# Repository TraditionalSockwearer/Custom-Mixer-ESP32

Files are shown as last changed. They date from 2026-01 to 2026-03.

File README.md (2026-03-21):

# Custom Mixer ESP32 (v2.0)

This project uses an ESP32 to read 5 linear faders, 2 rotary encoders, and 18 switches, with programmable buttons acting like MIDI and everything that happens, as a change in volume will show on the 2.2-inch screen.

This project's purpose is to act as a mixer and control the volume of an app when it sounds too loud or too quiet.

The Rotary Encoders will be used as a selector to scroll through active apps and the slider they should be on, or potentially as a master volume control.

## Schematic



## PCB

aab3a241-1
aab3a241-2

## CAD





## Quick Start

### 1. Flash the ESP32-S3 Firmware

1. Install [CircuitPython 9.x](https://circuitpython.org/board/espressif_esp32s3_devkitc_1_n8r8/) on your ESP32-S3
2. Copy `Firmware/esp32/main.py` and `Firmware/esp32/boot.py` to the **CIRCUITPY** drive
3. Copy these libraries to the `/lib` folder on the drive (from the [CircuitPython Bundle](https://circuitpython.org/libraries)):
   - `adafruit_ili9341.mpy`
   - `adafruit_display_text/`
   - `adafruit_bus_device/`

### 2. Run the PC Software

```bash
pip install pycaw pyserial pystray psutil Pillow pywin32 obs-websocket-py
python Firmware/mixer.py --console
```

Run `python Firmware/mixer.py --help` for all options (COM port override, test mode, etc.).

> Requires **Windows 10/11**, **Python 3.10+**, and optionally **EqualizerAPO** (for EQ mode) and **OBS with WebSocket** (for OBS channel).

## Firmware

[View detailed firmware documentation](Firmware/README.md)

## BOM

The complete list of hardware required to build this project.

### Digikey

| Part | Description | Qty | Price |
| :--- | :--- | :--- | :--- |
| **[PTA6043-2015CPB103](https://www.digikey.co.uk/en/products/detail/bourns-inc/PTA6043-2015CPB103/3781230)** | Bourns — Slide Pot 10K, 60mm | 5 | £7.10 |
| **[K104K10X7RF5UH5](https://www.digikey.co.uk/en/products/detail/vishay-beyschlag-draloric-bc-components/K104K10X7RF5UH5/2356754)** | Vishay — Ceramic Cap 0.1µF 50V | 10 | £1.13 |
| **[ECA-1EM101B](https://www.digikey.co.uk/en/products/detail/panasonic-electronic-components/ECA-1EM101B/268461)** | Panasonic — Electrolytic Cap 100µF 25V | 2 | £0.46 |
| **[PEC11R-4215F-S0024](https://www.digikey.co.uk/en/products/detail/bourns-inc/PEC11R-4215F-S0024/4499665)** | Bourns — Rotary Encoder | 2 | £3.30 |
| **[PRPC040SAAN-RC](https://www.digikey.co.uk/en/products/detail/sullins-connector-solutions/PRPC040SAAN-RC/2775214)** | Sullins — 40-Pin Header | 3 | £1.23 |
| **[RNF14FTD10K0](https://www.digikey.co.uk/en/products/detail/stackpole-electronics-inc/RNF14FTD10K0/1706596)** | Stackpole — 10K Resistor 1/4W | 10 | £0.30 |
| **[CFR-50JT-52-4K7](https://www.digikey.co.uk/en/products/detail/yageo/CFR-50JT-52-4K7/9099664)** | YAGEO — 4.7K Resistor 1/2W | 10 | £0.34 |
| **[OEJL-90-4-5](https://www.digikey.co.uk/en/products/detail/kilo-international/OEJL-90-4-5/710678)** | Kilo International — Solid Aluminium Knob | 2 | £18.68 |
| **[1300-B](https://www.digikey.co.uk/en/products/detail/davies-molding-llc/1300-B/7908413)** | Davies Molding — Nylon Knob | 5 | £3.86 |
| **[MCP23017-E/SP](https://www.digikey.co.uk/en/products/detail/microchip-technology/MCP23017-E-SP/894272)** | Microchip — I²C I/O Expander 28-SDIP | 2 | £2.54 |

Digikey Total: £45.37

### AliExpress

| Part | Description | Qty | Price |
| :--- | :--- | :--- | :--- |
| **[2.2" TFT LCD](https://www.aliexpress.com/item/1005008143782445.html)** | 2.2" ILI9341 Full Color TFT (includes shipping) | 1 | £5.22 + £3.32 shipping |
| **[ESP32-S3-WROOM-1 N16R8](https://www.aliexpress.com/item/1005008796158734.html)** | ESP32-S3 Dev Board, 44-Pin, 8M PSRAM | 1 | £5.28 |
| **Cherry MX Switches** | Pre-owned mechanical switches | 18 | £0.00 |

Estimated AliExpress Total: £13.82 without discount

### Manufacturing

| Part | Description | Qty | Price |
| :--- | :--- | :--- | :--- |
| **[JLCPCB PCB](https://jlcpcb.com/)** | PCB prototype (black, 1.6mm, HASL with lead) | 5 | $13.10 |

JLCPCB Total: $21.08 or £15.80

For 3D printing, filament is about £10.25 from Bambu Labs.

**Grand Total: £85.24**

## KiCad Libraries

- [SSD1306 OLED Footprint](https://github.com/gorbachev/KiCad-SSD1306-0.91-OLED-4pin-128x32.pretty/tree/master)
- [ESP32-DEVKITC-32E](https://www.snapeda.com/parts/ESP32-DEVKITC-32E/Espressif%20Systems/view-part/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)
- [PEC12R Rotary Encoder](https://www.snapeda.com/parts/PEC12R-4217F-S0024/Bourns/view-part/?ref=search&t=rotary%20encoder)
- [Adafruit 2717](https://www.snapeda.com/parts/2717/Adafruit%20Industries/view-part/)
- [PTA4543 Slide Pot](https://www.snapeda.com/parts/PTA4543-2015DPA103/Bourns/view-part/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)
- [0.91" OLED 3D Model](https://grabcad.com/library/0-91-oled-display-module-1/files?folder_id=13981557)

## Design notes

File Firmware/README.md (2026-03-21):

# Custom Mixer

Companion software and firmware for a custom digital mixer built around an ESP32-S3.

## Overview

5 faders, 2 rotary encoders, and a 2.2" color TFT on an ESP32-S3. Controls system audio, per-app volume, microphone input, OBS, and headphone EQ from one device.

## Structure

```
mixer.py              ← single PC script (run this)
Firmware/esp32/       ← CircuitPython firmware for ESP32-S3
```

### Channel Layout

| Fader | Control |
|---|---|
| 1 | Master Volume |
| 2 | App 1 (cycle with encoder) |
| 3 | App 2 (cycle with encoder) |
| 4 | Microphone Input |
| 5 | OBS Desktop Audio |

### EQ Mode

Button 1 toggles EQ mode — faders map to 80Hz, 320Hz, 1kHz, 3.2kHz, 10kHz via EqualizerAPO.

## Usage

```bash
pip install pycaw pyserial pystray psutil Pillow pywin32 obs-websocket-py
python mixer.py --console
```

### Options
```
--port, -p    COM port (auto-detected if omitted)
--console, -c Run without system tray
--test, -t    Print audio sessions and exit
```

## Requirements
- Python 3.10+
- Windows 10/11
- EqualizerAPO (for EQ mode)
- OBS with WebSocket enabled (for OBS channel)

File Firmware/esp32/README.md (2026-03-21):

# ESP32-S3 Mixer Firmware

CircuitPython firmware for the Custom Mixer running on an ESP32-S3 with a 2.2" TFT display.

## Hardware

- ESP32-S3 devboard
- 2.2" ILI9341 SPI TFT (320x240, full color)
- 5x Linear faders (analog)
- 2x Rotary encoders with push buttons

### Wiring

| Component | Pin |
|---|---|
| TFT SCK | IO18  |
| TFT MOSI  | IO23  |
| TFT MISO  | IO19  |
| TFT CS | IO15  |
| TFT DC | IO2 |
| TFT RST | IO4 |
| Fader 1 | IO32  |
| Fader 2 | IO33  |
| Fader 3 | IO34  |
| Fader 4 | IO35  |
| Fader 5 | IO36  |
| Enc 1 A/B | IO25/IO26 |
| Enc 2 A/B | IO14/IO12 |
| Enc 1 Btn | IO27  |
| Enc 2 Btn | IO13  |

## Modes

### Volume Mixer
- 5 channel strips on one screen: Master, App 1, App 2, Mic, OBS
- Faders control per-channel volume
- Encoders cycle which app is assigned to channels 2 and 3
- Button 1 toggles between Volume and EQ mode
- Button 2 mutes the Master channel

### EQ Control
- Faders map to 5-band EQ: 80Hz, 320Hz, 1kHz, 3.2kHz, 10kHz
- Range: -15dB to +15dB
- Requires EqualizerAPO on the PC

## Installation

1. Install [CircuitPython 9.x](https://circuitpython.org/board/espressif_esp32s3_devkitc_1_n8r8/) on your ESP32-S3
2. Copy `main.py` and `boot.py` (both in this directory) to the **CIRCUITPY** drive
3. Copy these libraries to `/lib` (from the [CircuitPython Bundle](https://circuitpython.org/libraries)):
   - `adafruit_ili9341.mpy`
   - `adafruit_display_text/`
   - `adafruit_bus_device/`

## Serial Protocol

USB CDC at 115200 baud.

### PC → ESP32
```
APP:<ch>:<icon>:<name>:<vol>    Channel info
APPS:<count>                    Channel count
MODE:<mode>                     Switch mode
PING                            Keepalive
```

### ESP32 → PC
```
VOL:<ch>:<vol>                  Fader value (0-100)
SELECT:<ch>:<dir>               Encoder rotation
MODE:<mode>                     Mode change request
MUT:<ch>:<state>                Mute toggle
PONG                            Keepalive response
```

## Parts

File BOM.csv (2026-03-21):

Category | Part Name | Quantity | Price | Vendor Link
Slide Potentiometers | Bourns PTA6043-2015CPB103 | 5 | £7.10 | https://www.digikey.co.uk/en/products/detail/bourns-inc/PTA6043-2015CPB103/3781230
Ceramic Capacitors | Vishay K104K10X7RF5UH5 (0.1uF) | 10 | £1.13 | https://www.digikey.co.uk/en/products/detail/vishay-beyschlag-draloric-bc-components/K104K10X7RF5UH5/2356754
Electrolytic Capacitors | Panasonic ECA-1EM101B (100uF) | 2 | £0.46 | https://www.digikey.co.uk/en/products/detail/panasonic-electronic-components/ECA-1EM101B/268461
Rotary Encoders | Bourns PEC11R-4215F-S0024 | 2 | £3.30 | https://www.digikey.co.uk/en/products/detail/bourns-inc/PEC11R-4215F-S0024/4499665
Pin Headers | Sullins PRPC040SAAN-RC (40 Pin) | 3 | £1.23 | https://www.digikey.co.uk/en/products/detail/sullins-connector-solutions/PRPC040SAAN-RC/2775214
Resistors | Stackpole RNF14FTD10K0 (10K) | 10 | £0.30 | https://www.digikey.co.uk/en/products/detail/stackpole-electronics-inc/RNF14FTD10K0/1706596
Resistors | YAGEO CFR-50JT-52-4K7 (4.7K) | 10 | £0.34 | https://www.digikey.co.uk/en/products/detail/yageo/CFR-50JT-52-4K7/9099664
Premium Knobs | Kilo International OEJL-90-4-5 (Solid Alum) | 2 | £18.68 | https://www.digikey.co.uk/en/products/detail/kilo-international/OEJL-90-4-5/710678
Standard Knobs | Davies Molding 1300-B (Nylon) | 5 | £3.86 | https://www.digikey.co.uk/en/products/detail/davies-molding-llc/1300-B/7908413
I2C Expander | Microchip MCP23017-E/SP | 2 | £2.54 | https://www.digikey.co.uk/en/products/detail/microchip-technology/MCP23017-E-SP/894272
Microcontroller | ESP32-S3-WROOM-1 N16R8 | 1 | £5.28 | https://www.aliexpress.com/item/1005008796158734.html
Screen | 2.2" TFT Full Color Screen LCD | 1 | £8.54 | https://www.aliexpress.com/item/1005008143782445.html
Switches | Cherry Mx Switches (Pre Owned) | 18 | £0.00
PCB Manufacturing | JLCPCB GerberFiles | 5 | $13.10 | https://jlcpcb.com/
3D Printing | Bambu Labs Filament | 1 | £10.25
Total | £85.24

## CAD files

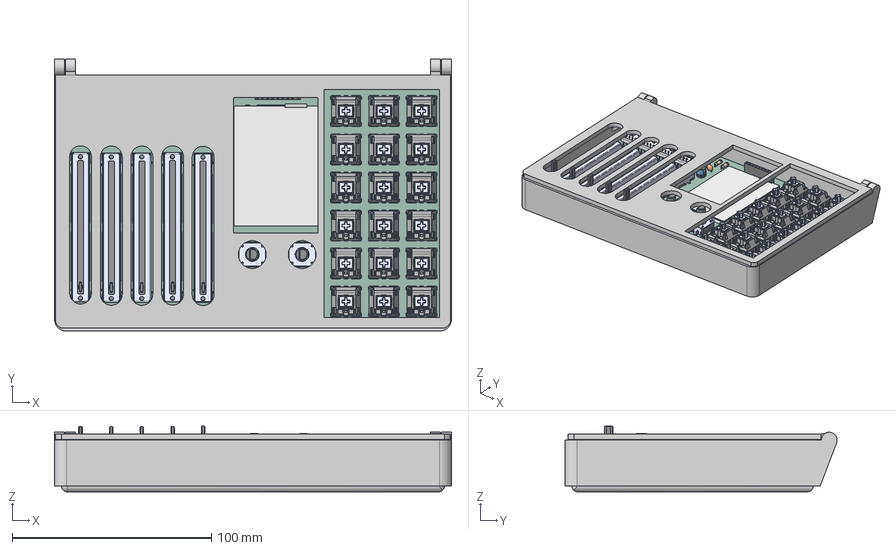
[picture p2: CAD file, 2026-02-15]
CAD/Complete Model.step
199.3 x 136.7 x 33.1 mm
60315CP x 5
PEC12R-4017F-S0024 x 2
C_Disc_D5.0mm_W2.5mm_P2.50mm x 7
PinSocket_1x09_P2.54mm_Vertical
R_Axial_DIN0207_L6.3mm_D2.5mm_P7.62mm_Horizontal x 3
CP_Radial_D6.3mm_P2.50mm
DIP-28_W7.62mm
Custom-Mixer-ESP32_PCB
frame
main_cable
light_cable
tft_matrix
tft_board
screen_film
screen_glass
touch_routs
touch_protect
touch_cable_contacts
touch_cable_film
esp32-wroom-1

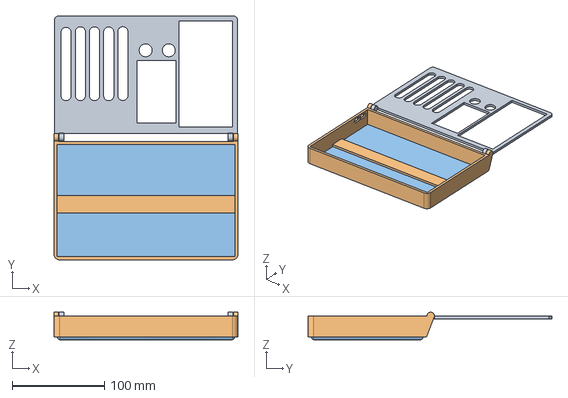
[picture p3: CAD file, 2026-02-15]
CAD/Enclosure.step
199.3 x 263.9 x 30.0 mm

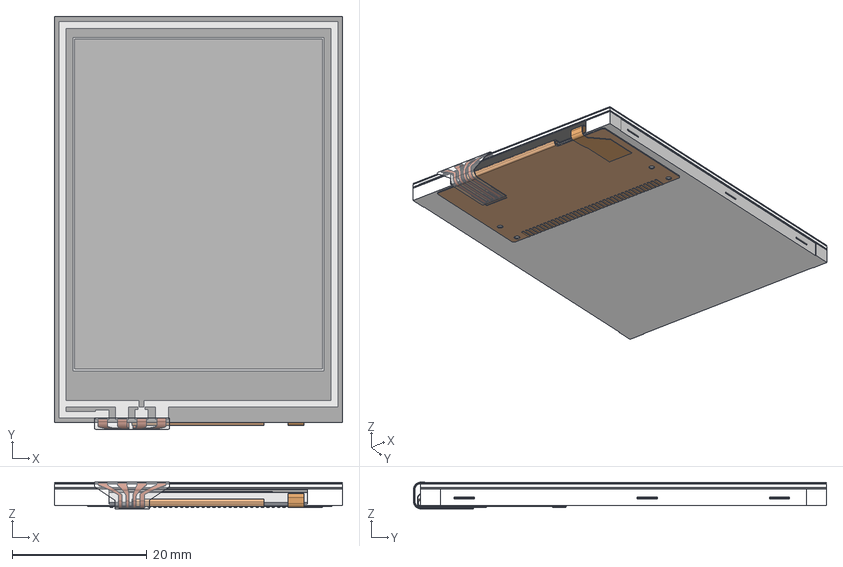
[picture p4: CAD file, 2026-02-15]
CAD/Model Used/2.4_TFT_Display.step
42.7 x 61.3 x 3.96 mm
frame
main_cable
light_cable
tft_matrix
tft_board
screen_film
screen_glass
touch_routs
touch_protect
touch_cable_contacts
touch_cable_film

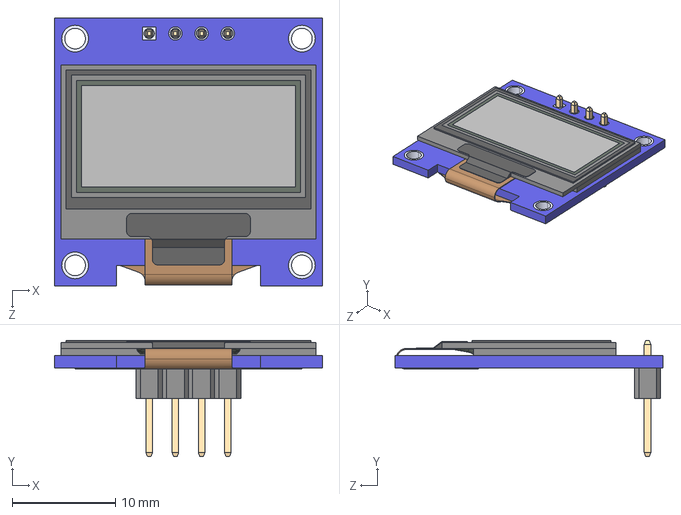
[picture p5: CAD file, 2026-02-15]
Custom-Mixer-Kicad/Oled Screen 128x64/DM-OLED096-636.step
26.0 x 11.3 x 26.0 mm
DM-OLED096-636_Module
DM-OLED096-636_Panel

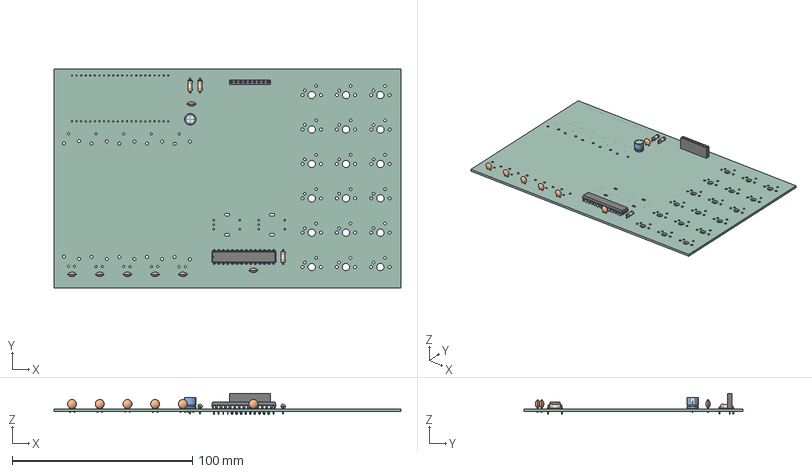
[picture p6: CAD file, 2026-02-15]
CAD/Model Used/Custom-Mixer-ESP32.step
192.3 x 121.2 x 11.8 mm
C_Disc_D5.0mm_W2.5mm_P2.50mm x 7
PinSocket_1x09_P2.54mm_Vertical
R_Axial_DIN0207_L6.3mm_D2.5mm_P7.62mm_Horizontal x 3
CP_Radial_D6.3mm_P2.50mm
DIP-28_W7.62mm
Custom-Mixer-ESP32_PCB

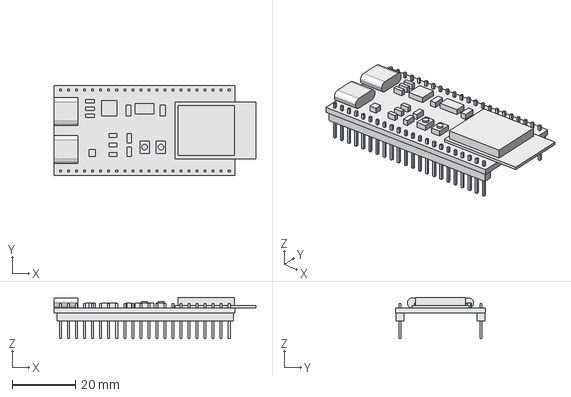
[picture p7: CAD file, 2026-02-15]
CAD/Model Used/esp32devkit-esp32-wroom-1.step
63.8 x 28.5 x 13.1 mm

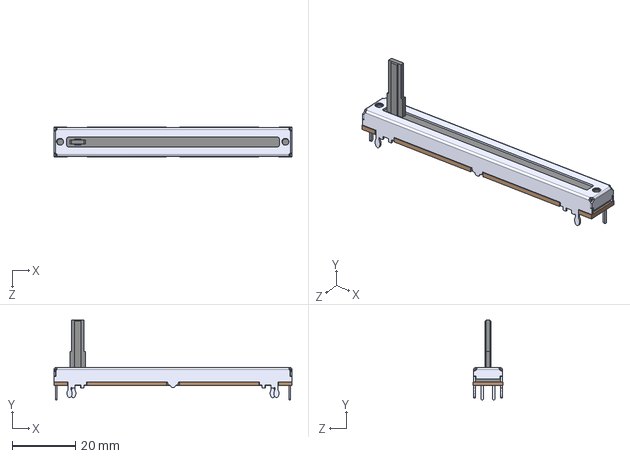
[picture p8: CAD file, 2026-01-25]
CAD/Model Used/PTA6043-2015CPB103--3DModel-STEP-269445.STEP
75.0 x 25.2 x 9.40 mm

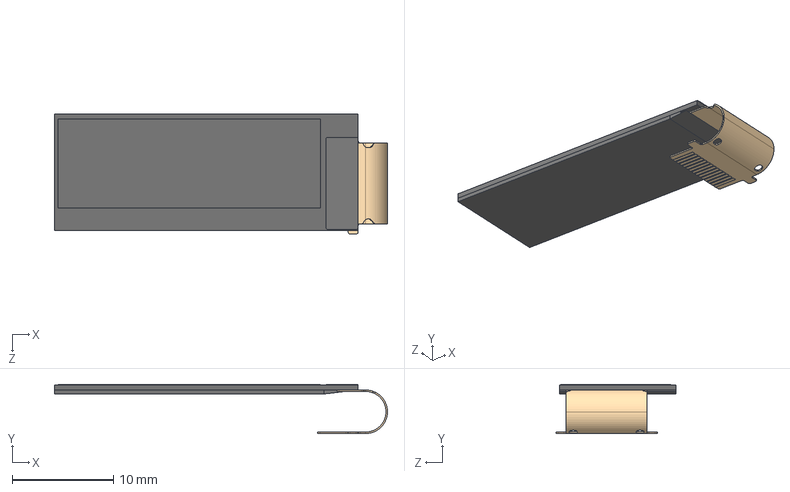
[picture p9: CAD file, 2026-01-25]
CAD/Model Used/ER-OLED0.91-3.STEP
32.9 x 4.88 x 11.9 mm

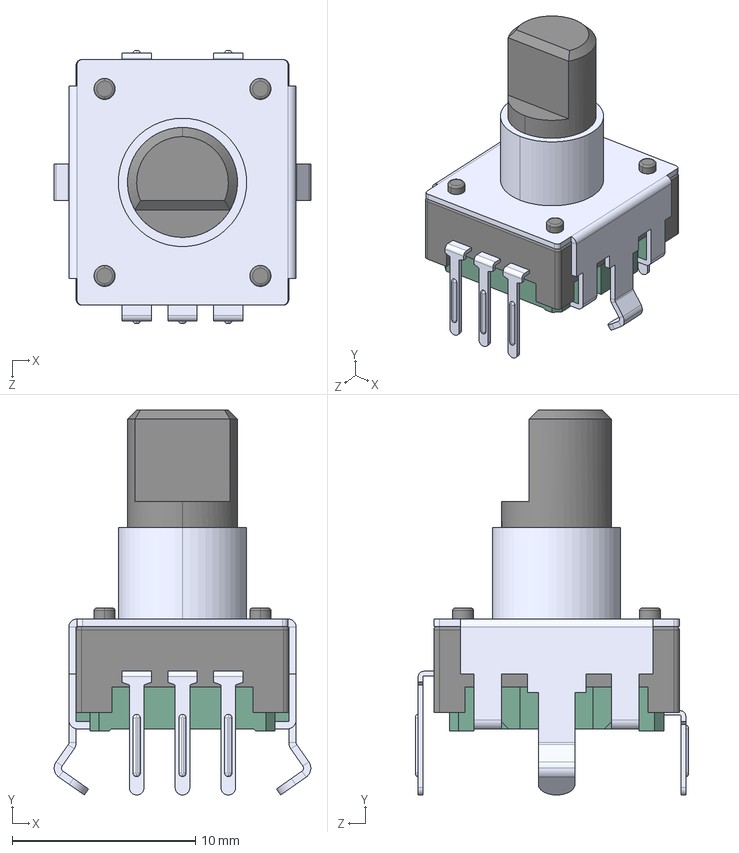
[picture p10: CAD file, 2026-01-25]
CAD/Model Used/PEC12R-4217F-S0024--3DModel-STEP-510211.STEP
14.0 x 21.0 x 14.9 mm

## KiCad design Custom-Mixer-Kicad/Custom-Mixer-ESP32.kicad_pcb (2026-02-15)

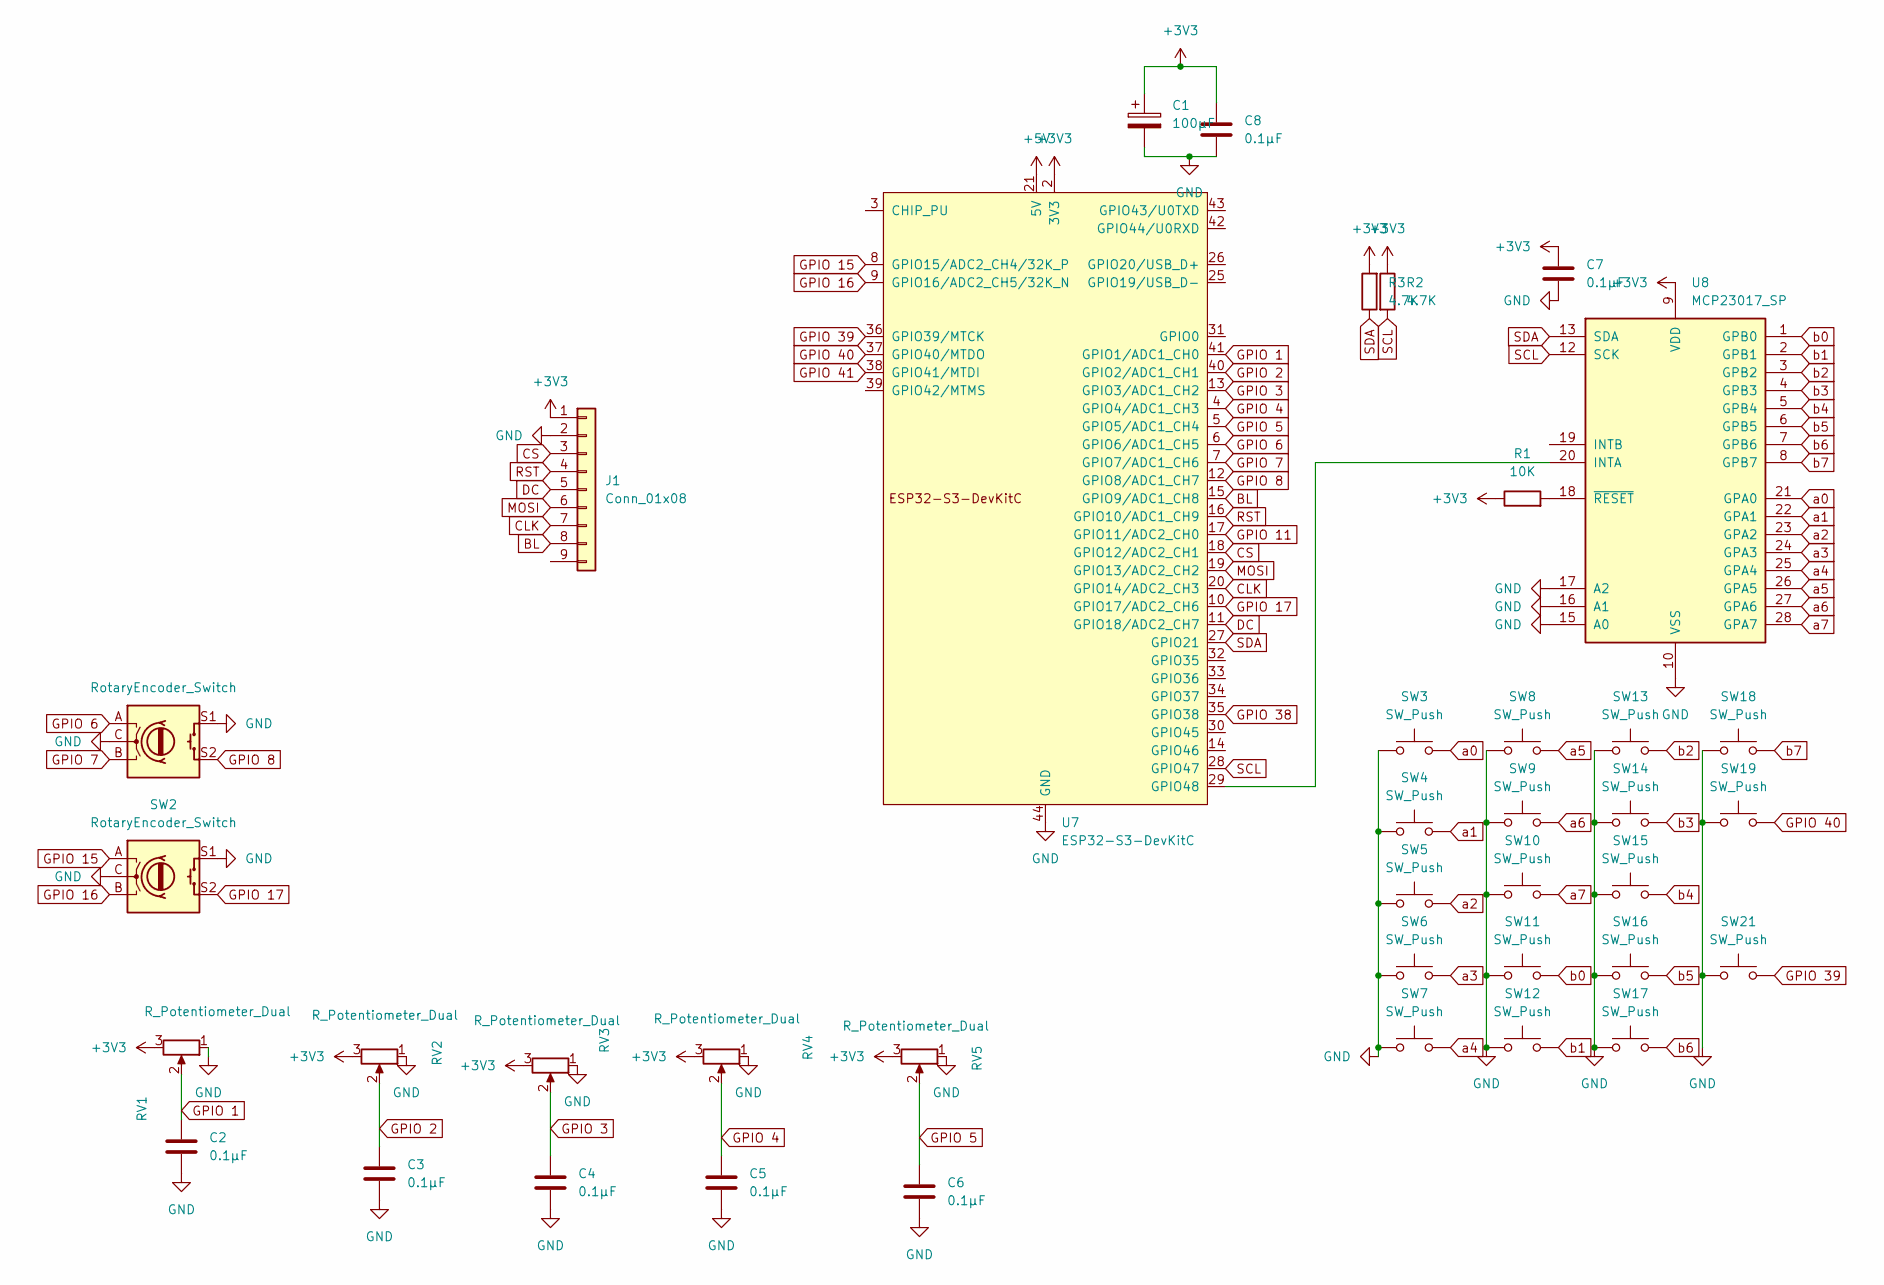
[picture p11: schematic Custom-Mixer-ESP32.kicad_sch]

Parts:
C1: 100µF; CP_Radial_D6.3mm_P2.50mm
C2, C3, C4, C5, C6, C7, C8: 0.1µF; C_Disc_D5.0mm_W2.5mm_P2.50mm
J1: Conn_01x08; PinSocket_1x09_P2.54mm_Vertical
R1: 10K; R_Axial_DIN0207_L6.3mm_D2.5mm_P7.62mm_Horizontal
R2, R3: 4.7K; R_Axial_DIN0207_L6.3mm_D2.5mm_P7.62mm_Horizontal
RV1, RV2, RV3, RV4, RV5: R_Potentiometer_Dual; Potentiometer_Bourns_PTA6043_Single_Slide
SW1, SW2: RotaryEncoder_Switch; RotaryEncoder_Alps_EC11E-Switch_Vertical_H20mm
SW3, SW4, SW5, SW6, SW7, SW8, SW9, SW10, SW11, SW12, SW13, SW14, SW15, SW16, SW17, SW18, SW19, SW21: SW_Push; SW_Cherry_MX_1.00u_PCB
U7: ESP32-S3-DevKitC
U8: MCP23017_SP; DIP-28_W7.62mm

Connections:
+3V3: C1.1, C7.1, C8.1, J1.1, R1.1, R2.1, R3.2, RV1.3, RV2.3, RV3.3, RV4.3, RV5.3, U7.1 (3V3), U7.2 (3V3), U8.9 (VDD)
+5V: U7.21 (5V)
BL: J1.8, U7.15 (GPIO9/ADC1_CH8)
CLK: J1.7, U7.20 (GPIO14/ADC2_CH3)
CS: J1.3, U7.18 (GPIO12/ADC2_CH1)
DC: J1.5, U7.11 (GPIO18/ADC2_CH7)
GND: C1.2, C2.2, C3.2, C4.2, C5.2, C6.2, C7.2, C8.2, J1.2, RV1.1, RV2.1, RV3.1, RV4.1, RV5.1, SW1.C, SW1.S1, SW2.C, SW2.S1, SW3.1, SW4.1, SW5.1, SW6.1, SW7.1, SW8.1, SW9.1, SW10.1, SW11.1, SW12.1, SW13.1, SW14.1, SW15.1, SW16.1, SW17.1, SW18.1, SW19.1, SW21.1, U7.22 (GND), U7.23 (GND), U7.24 (GND), U7.44 (GND), U8.10 (VSS), U8.15 (A0), U8.16 (A1), U8.17 (A2)
GPIO 1: C2.1, RV1.2, U7.41 (GPIO1/ADC1_CH0)
GPIO 2: C3.1, RV2.2, U7.40 (GPIO2/ADC1_CH1)
GPIO 3: C4.1, RV3.2, U7.13 (GPIO3/ADC1_CH2)
GPIO 4: C5.1, RV4.2, U7.4 (GPIO4/ADC1_CH3)
GPIO 5: C6.1, RV5.2, U7.5 (GPIO5/ADC1_CH4)
GPIO 6: SW1.A, U7.6 (GPIO6/ADC1_CH5)
GPIO 7: SW1.B, U7.7 (GPIO7/ADC1_CH6)
GPIO 8: SW1.S2, U7.12 (GPIO8/ADC1_CH7)
GPIO 11: U7.17 (GPIO11/ADC2_CH0)
GPIO 15: SW2.A, U7.8 (GPIO15/ADC2_CH4/32K_P)
GPIO 16: SW2.B, U7.9 (GPIO16/ADC2_CH5/32K_N)
GPIO 17: SW2.S2, U7.10 (GPIO17/ADC2_CH6)
GPIO 38: U7.35 (GPIO38)
GPIO 39: SW21.2, U7.36 (GPIO39/MTCK)
GPIO 40: SW19.2, U7.37 (GPIO40/MTDO)
GPIO 41: U7.38 (GPIO41/MTDI)
MOSI: J1.6, U7.19 (GPIO13/ADC2_CH2)
unnamed: U7.29 (GPIO48), U8.20 (INTA)
unnamed: R1.2, U8.18 (~RESET)
RST: J1.4, U7.16 (GPIO10/ADC1_CH9)
SCL: R2.2, U7.28 (GPIO47), U8.12 (SCK)
SDA: R3.1, U7.27 (GPIO21), U8.13 (SDA)
a0: SW3.2, U8.21 (GPA0)
a1: SW4.2, U8.22 (GPA1)
a2: SW5.2, U8.23 (GPA2)
a3: SW6.2, U8.24 (GPA3)
a4: SW7.2, U8.25 (GPA4)
a5: SW8.2, U8.26 (GPA5)
a6: SW9.2, U8.27 (GPA6)
a7: SW10.2, U8.28 (GPA7)
b0: SW11.2, U8.1 (GPB0)
b1: SW12.2, U8.2 (GPB1)
b2: SW13.2, U8.3 (GPB2)
b3: SW14.2, U8.4 (GPB3)
b4: SW15.2, U8.5 (GPB4)
b5: SW16.2, U8.6 (GPB5)
b6: SW17.2, U8.7 (GPB6)
b7: SW18.2, U8.8 (GPB7)

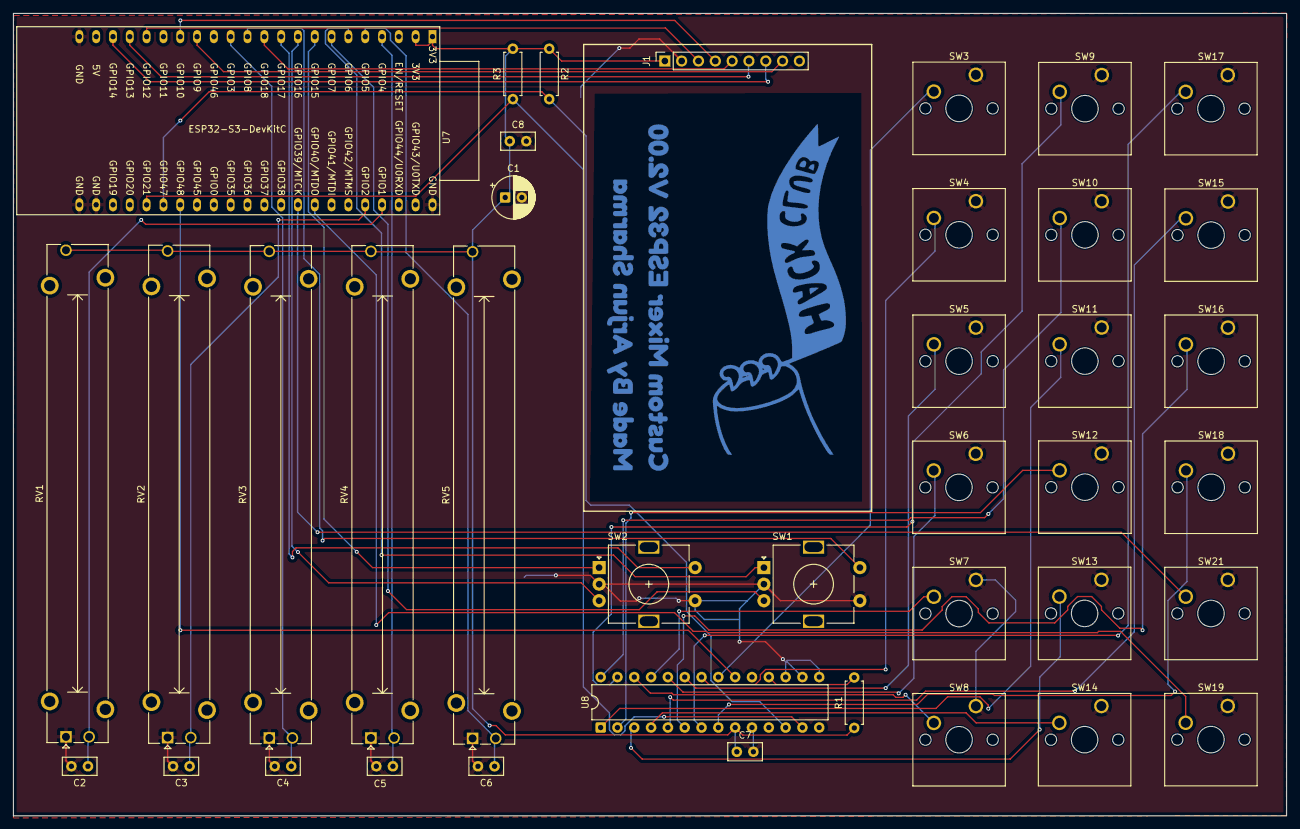
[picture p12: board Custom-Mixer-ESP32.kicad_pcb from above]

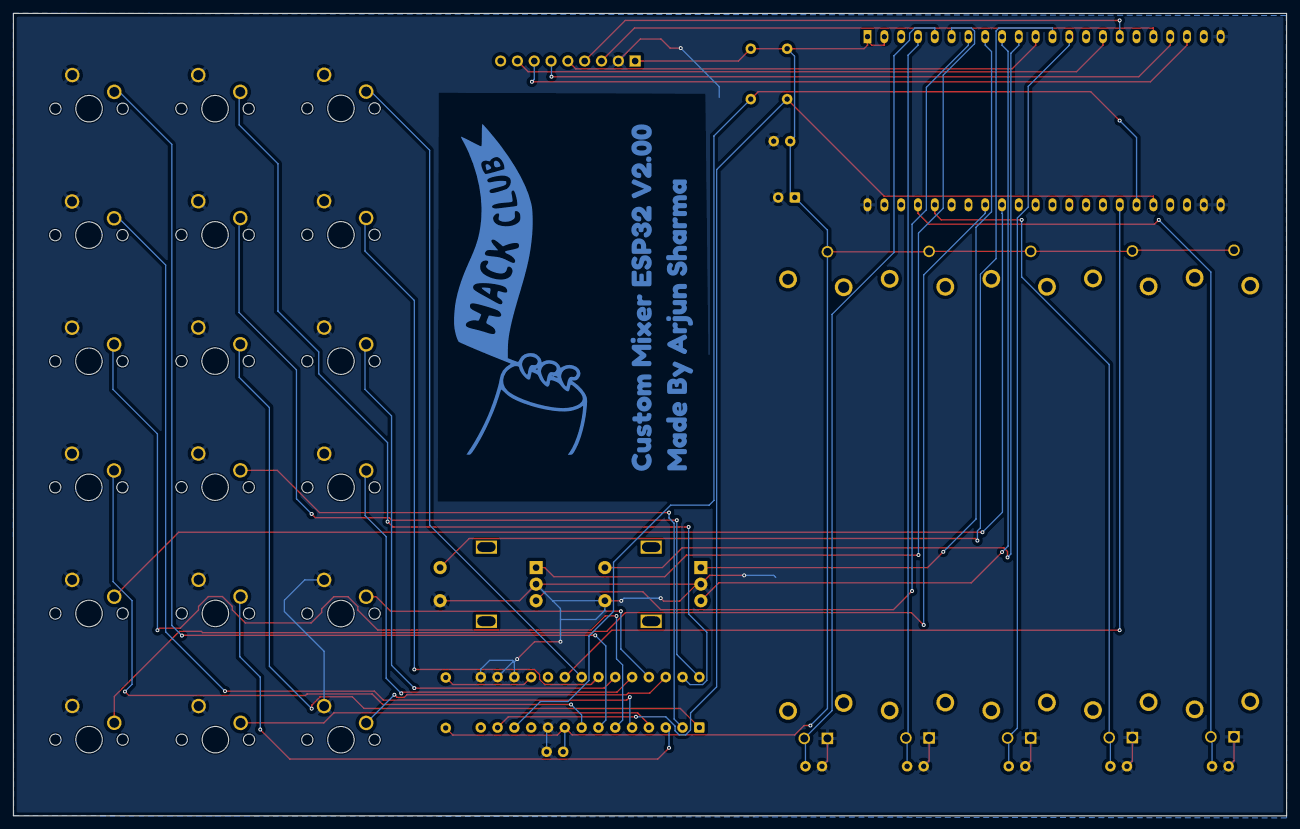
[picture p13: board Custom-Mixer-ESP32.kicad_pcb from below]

Board: 2 copper layers, 192.3 x 121.2 mm, 41 parts (2 on the bottom side), 41 nets.

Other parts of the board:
Goo: LOGO; Hackclublogo(fmask)
kibuzzard-698F8E64: G***; kibuzzard-698F8E64

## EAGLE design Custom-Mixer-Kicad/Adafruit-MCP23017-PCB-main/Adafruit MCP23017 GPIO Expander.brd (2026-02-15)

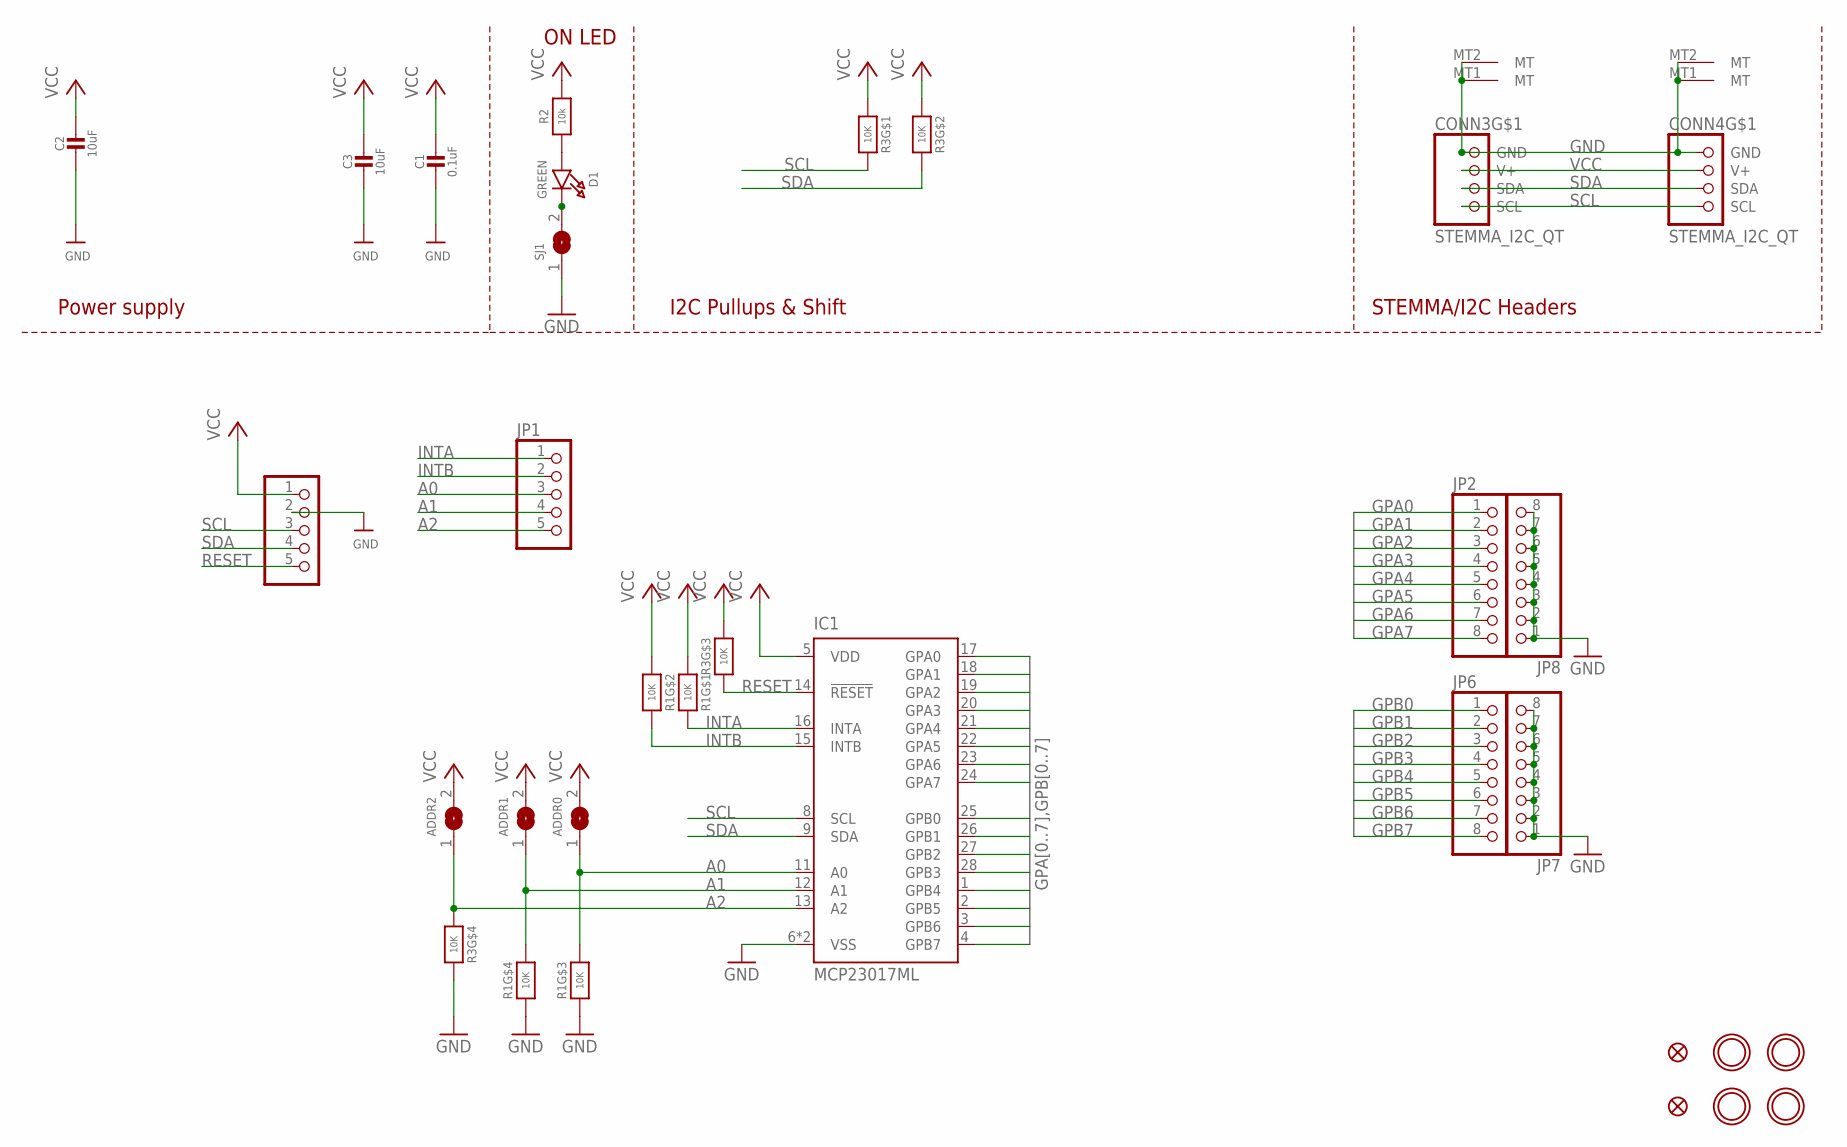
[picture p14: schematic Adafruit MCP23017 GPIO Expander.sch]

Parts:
ADDR0, ADDR1, ADDR2: SOLDERJUMPER; SOLDERJUMPER_ARROW_NOPASTE
C1: 0.1uF; 0603-NO
C2, C3: 10uF; 0805-NO
CONN3, CONN4: STEMMA_I2C_QT; JST_SH4
D1: GREEN; CHIPLED_0603_NOOUTLINE
FID3, FID4: FIDUCIAL_1MM
IC1: MCP23017ML; QFN28-ML_6X6MM
JP1, JP5: HEADER-1X570MIL; 1X05_ROUND_70
JP2, JP6, JP7, JP8: HEADER-1X870MIL; 1X08_ROUND_70
R1, R3: 10K; RESPACK_4X0603
R2: 10k; 0603-NO
SJ1: SOLDERJUMPERCLOSED; SOLDERJUMPER_CLOSEDWIRE
U$1, U$17, U$19, U$21: MOUNTINGHOLE2.5; MOUNTINGHOLE_2.5_PLATED

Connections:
A0: ADDR0.1, IC1.11 (A0), JP1.3, R1.6 (2)
A1: ADDR1.1, IC1.12 (A1), JP1.4, R1.5 (2)
A2: ADDR2.1, IC1.13 (A2), JP1.5, R3.4 (1)
GND: C1.2, C2.2, C3.2, CONN3.1 (GND), CONN3.MT1 (MT), CONN3.MT2 (MT), CONN4.1 (GND), CONN4.MT1 (MT), CONN4.MT2 (MT), IC1.6 (VSS), IC1.EXP (VSS), JP5.2, JP7.1, JP7.2, JP7.3, JP7.4, JP7.5, JP7.6, JP7.7, JP7.8, JP8.1, JP8.2, JP8.3, JP8.4, JP8.5, JP8.6, JP8.7, JP8.8, R1.3 (1), R1.4 (1), R3.5 (2), SJ1.1
GPA0: IC1.17 (GPA0), JP2.1
GPA1: IC1.18 (GPA1), JP2.2
GPA2: IC1.19 (GPA2), JP2.3
GPA3: IC1.20 (GPA3), JP2.4
GPA4: IC1.21 (GPA4), JP2.5
GPA5: IC1.22 (GPA5), JP2.6
GPA6: IC1.23 (GPA6), JP2.7
GPA7: IC1.24 (GPA7), JP2.8
GPB0: IC1.25 (GPB0), JP6.1
GPB1: IC1.26 (GPB1), JP6.2
GPB2: IC1.27 (GPB2), JP6.3
GPB3: IC1.28 (GPB3), JP6.4
GPB4: IC1.1 (GPB4), JP6.5
GPB5: IC1.2 (GPB5), JP6.6
GPB6: IC1.3 (GPB6), JP6.7
GPB7: IC1.4 (GPB7), JP6.8
INTA: IC1.16 (INTA), JP1.1, R1.8 (2)
INTB: IC1.15 (INTB), JP1.2, R1.7 (2)
unnamed: D1.A, R2.1
unnamed: D1.C, SJ1.2
RESET: IC1.14 (!RESET), JP5.5, R3.3 (1)
SCL: CONN3.4 (SCL), CONN4.4 (SCL), IC1.8 (SCL), JP5.3, R3.8 (2)
SDA: CONN3.3 (SDA), CONN4.3 (SDA), IC1.9 (SDA), JP5.4, R3.7 (2)
VCC: ADDR0.2, ADDR1.2, ADDR2.2, C1.1, C2.1, C3.1, CONN3.2 (V+), CONN4.2 (V+), IC1.5 (VDD), JP5.1, R1.1, R1.2 (1), R2.2, R3.1, R3.2 (1), R3.6 (2)

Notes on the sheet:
I2C Pullups & Shift
STEMMA/I2C Headers
ON LED
Power supply

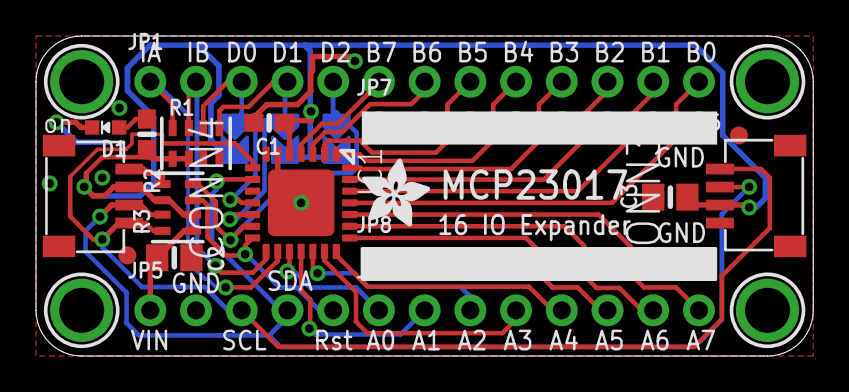
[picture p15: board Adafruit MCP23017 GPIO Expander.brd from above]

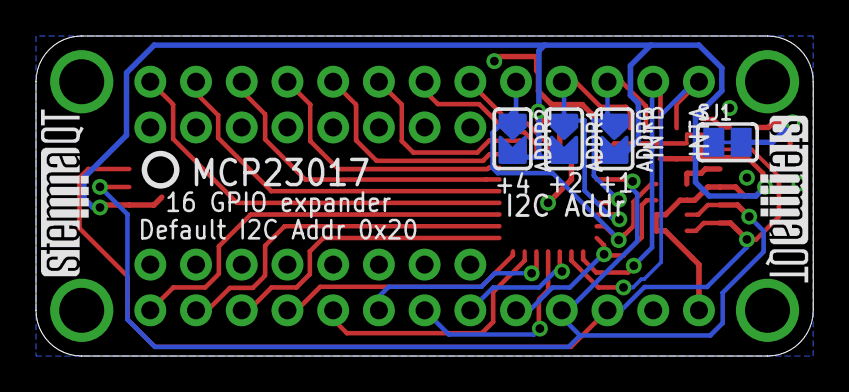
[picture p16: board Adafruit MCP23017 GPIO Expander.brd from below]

Board: 2 copper layers, 43.2 x 17.8 mm, 30 parts (7 on the bottom side), 28 nets.

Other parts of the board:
U$22: ADAFRUIT_3.5MM
U$25: PCBFEAT-REV-040
U$30, U$31: STEMMAQT

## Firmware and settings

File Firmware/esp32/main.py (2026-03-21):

import time
import board
import analogio
import rotaryio
import keypad
import usb_cdc
import displayio
import terminalio
import microcontroller
from adafruit_display_text import label
from adafruit_ili9341 import ILI9341

TFT_CLK = board.IO18
TFT_MOSI = board.IO23
TFT_MISO = board.IO19
TFT_CS = board.IO15
TFT_DC = board.IO2
TFT_RST = board.IO4

FADER_PINS = (board.IO32, board.IO33, board.IO34, board.IO35, board.IO36)
ENCODER_ROTARY_PINS = ((board.IO25, board.IO26), (board.IO14, board.IO12))
ENCODER_SWITCH_PINS = (board.IO27, board.IO13)

COLOR_MASTER = 0xFFD700
COLOR_APP    = 0x00CED1
COLOR_MIC    = 0xFF4500
COLOR_OBS    = 0x9370DB
COLOR_MUTED  = 0x808080
COLOR_BG     = 0x000000

MODE_VOLUME = "VOLUME"
MODE_EQ = "EQ"
MODES = [MODE_VOLUME, MODE_EQ]

VOLUME_LABELS = ["MASTER", "APP 1", "APP 2", "MIC", "OBS"]
EQ_LABELS = ["80Hz", "320Hz", "1kHz", "3.2kHz", "10kHz"]
STRIP_COLORS = [COLOR_MASTER, COLOR_APP, COLOR_APP, COLOR_MIC, COLOR_OBS]


class ChannelStrip:
    def __init__(self, x, width, height, color):
        self.group = displayio.Group(x=x)
        self.width = width
        self.height = height
        self.color = color

        border = displayio.Bitmap(width - 4, height, 1)
        pal = displayio.Palette(2)
        pal[0] = COLOR_BG
        pal[1] = color
        self.group.append(displayio.TileGrid(border, pixel_shader=pal, x=2, y=0))

        self.name_label = label.Label(terminalio.FONT, text="---", color=0xFFFFFF, x=5, y=10)
        self.group.append(self.name_label)

        self.bar_bg = displayio.Bitmap(width - 20, height - 60, 2)
        bar_pal = displayio.Palette(3)
        bar_pal[0] = 0x222222
        bar_pal[1] = color
        bar_pal[2] = COLOR_MUTED
        bar_group = displayio.Group(x=10, y=30)
        bar_group.append(displayio.TileGrid(self.bar_bg, pixel_shader=bar_pal))
        self.group.append(bar_group)

        self.pct_label = label.Label(terminalio.FONT, text="0%", color=0xFFFFFF, x=15, y=height - 15)
        self.group.append(self.pct_label)

    def update(self, name, vol, muted=False):
        self.name_label.text = name[:8]
        self.pct_label.text = f"{vol}%"

        bar_h = self.bar_bg.height
        fill_h = int((vol / 100) * bar_h)

        self.bar_bg.fill(0)
        idx = 2 if muted else 1
        for y in range(bar_h - fill_h, bar_h):
            for x in range(self.bar_bg.width):
                self.bar_bg[x, y] = idx


class MixerFirmware:
    def __init__(self):
        self.mode = MODE_VOLUME
        self.labels = VOLUME_LABELS.copy()
        self.volumes = [0] * 5
        self.mutes = [False] * 5
        self.last_fader_vals = [-1] * 5
        self.last_enc_pos = [0, 0]

        self._init_display()
        self._init_faders()
        self._init_encoders()
        self._init_serial()

    def _init_display(self):
        displayio.release_displays()
        spi = board.SPI()
        bus = displayio.FourWire(spi, command=TFT_DC, chip_select=TFT_CS, reset=TFT_RST)
        self.display = ILI9341(bus, width=320, height=240, rotation=90)

        self.root = displayio.Group()
        self.display.show(self.root)

        bg = displayio.Bitmap(320, 240, 1)
        bg_pal = displayio.Palette(1)
        bg_pal[0] = COLOR_BG
        self.root.append(displayio.TileGrid(bg, pixel_shader=bg_pal))

        self.strips = []
        for i in range(5):
            strip = ChannelStrip(i * 64, 64, 240, STRIP_COLORS[i])
            self.strips.append(strip)
            self.root.append(strip.group)

    def _init_faders(self):
        self.faders = [analogio.AnalogIn(pin) for pin in FADER_PINS]
        self.fader_buf = [[0] * 10 for _ in range(5)]

    def _init_encoders(self):
        self.encoders = [
            rotaryio.IncrementalEncoder(a, b) for a, b in ENCODER_ROTARY_PINS
        ]
        self.keys = keypad.Keys(ENCODER_SWITCH_PINS, value_when_pressed=False, pull=True)

    def _init_serial(self):
        self.serial = usb_cdc.data if usb_cdc.data else usb_cdc.console

    def smooth_fader(self, i):
        val = self.faders[i].value
        buf = self.fader_buf[i]
        buf.pop(0)
        buf.append(val)
        return sum(buf) // len(buf)

    def send(self, msg):
        if self.serial:
            try:
                self.serial.write(f"{msg}\n".encode("utf-8"))
            except Exception:
                pass

    def read_serial(self):
        if not self.serial or not self.serial.in_waiting:
            return
        try:
            line = self.serial.readline().decode("utf-8").strip()
            if line:
                self.handle_command(line)
        except Exception:
            pass

    def handle_command(self, line):
        parts = line.split(":")
        if not parts:
            return
        cmd = parts[0]

        if cmd == "APP" and len(parts) >= 4:
            try:
                ch = int(parts[1])
                name = parts[3] if parts[3] else self.labels[ch]
                vol = int(parts[4]) if len(parts) > 4 else self.volumes[ch]
                if 0 <= ch < 5:
                    self.labels[ch] = name
                    self.volumes[ch] = vol
                    self.strips[ch].update(name, vol, self.mutes[ch])
            except (ValueError, IndexError):
                pass

        elif cmd == "PING":
            self.send("PONG")

        elif cmd == "MODE" and len(parts) >= 2:
            new_mode = parts[1]
            if new_mode in MODES and new_mode != self.mode:
                self.mode = new_mode
                microcontroller.reset()

    def run(self):
        if self.mode == MODE_VOLUME:
            self.labels = VOLUME_LABELS.copy()
        else:
            self.labels = EQ_LABELS.copy()

        for i in range(5):
            self.strips[i].update(self.labels[i], self.volumes[i], self.mutes[i])

        while True:
            self.read_serial()

            for i in range(5):
                raw = self.smooth_fader(i)
                vol = int((raw / 65535) * 100)
                if abs(vol - self.last_fader_vals[i]) > 1:
                    self.last_fader_vals[i] = vol
                    self.volumes[i] = vol
                    self.send(f"VOL:{i}:{vol}")
                    self.strips[i].update(self.labels[i], vol, self.mutes[i])

            for i, enc in enumerate(self.encoders):
                pos = enc.position
                delta = pos - self.last_enc_pos[i]
                if delta != 0:
                    self.send(f"SELECT:{1 + i}:{1 if delta > 0 else -1}")
                    self.last_enc_pos[i] = pos

            event = self.keys.events.get()
            if event and event.pressed:
                if event.key_number == 0:
                    self.mode = MODE_EQ if self.mode == MODE_VOLUME else MODE_VOLUME
                    self.send(f"MODE:{self.mode}")
                    microcontroller.reset()
                elif event.key_number == 1:
                    self.mutes[0] = not self.mutes[0]
                    self.send(f"MUT:0:{int(self.mutes[0])}")
                    self.strips[0].update(self.labels[0], self.volumes[0], self.mutes[0])

            time.sleep(0.01)


if __name__ == "__main__":
    MixerFirmware().run()

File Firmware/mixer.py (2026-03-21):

import os
import io
import time
import threading
import argparse
from typing import Optional, Dict, List, Callable, Set
from dataclasses import dataclass
from enum import Enum
from pathlib import Path

import serial
import serial.tools.list_ports
from ctypes import POINTER, cast
import comtypes
from comtypes import CLSCTX_ALL
from pycaw.pycaw import AudioUtilities, ISimpleAudioVolume
import psutil

try:
    from pycaw.pycaw import IAudioEndpointVolume
except ImportError:
    IAudioEndpointVolume = None

try:
    from obswebsocket import obsws, requests as obs_requests
    HAS_OBS = True
except ImportError:
    HAS_OBS = False

try:
    import pystray
    from PIL import Image, ImageDraw
    HAS_TRAY = True
except ImportError:
    HAS_TRAY = False

try:
    import win32gui
    import win32ui
    HAS_PYWIN32 = True
except ImportError:
    HAS_PYWIN32 = False

try:
    comtypes.CoInitialize()
except OSError:
    pass


# ── Data ─────────────────────────────────────────────────────────────────────

@dataclass
class AudioSession:
    process_id: int
    process_name: str
    display_name: str
    volume: float
    is_muted: bool
    def __hash__(self):
        return hash(self.process_id)

@dataclass
class EQBand:
    name: str
    frequency: int
    gain: float
    q: float


# ── Audio Controller ─────────────────────────────────────────────────────────

class AudioController:
    DISPLAY_NAMES = {
        'chrome.exe': 'Chrome', 'firefox.exe': 'Firefox', 'msedge.exe': 'Edge',
        'discord.exe': 'Discord', 'spotify.exe': 'Spotify', 'steam.exe': 'Steam',
        'vlc.exe': 'VLC', 'obs64.exe': 'OBS', 'explorer.exe': 'System',
        'audiodg.exe': 'System Audio', 'signalrgb.exe': 'SignalRGB',
        'signalrgbcore.exe': 'SignalRGB',
    }
    BLOCKED_APPS = {
        'grammarly.exe', 'grammarlydesktop.exe', 'grammarly.desktop.exe',
        'antivirus', 'avgui.exe', 'avast', 'norton', 'mcafee',
        'searchhost.exe', 'searchapp.exe', 'runtimebroker.exe',
        'backgroundtaskhost.exe', 'shellexperiencehost.exe',
        'startmenuexperiencehost.exe', 'lockapp.exe', 'textinputhost.exe',
    }

    def __init__(self):
        self._master_volume = None
        self._input_volume = None
        self._callbacks: List[Callable] = []
        self._monitor_thread: Optional[threading.Thread] = None
        self._running = False
        self._init_master()
        self._init_input()

    def _init_master(self):
        try:
            devices = AudioUtilities.GetSpeakers()
            if hasattr(devices, 'EndpointVolume'):
                self._master_volume = devices.EndpointVolume
                return
            if hasattr(devices, '_volume'):
                self._master_volume = devices._volume
                return
            interface = devices.Activate(IAudioEndpointVolume._iid_, CLSCTX_ALL, None)
            self._master_volume = cast(interface, POINTER(IAudioEndpointVolume))
        except Exception:
            pass

    def _init_input(self):
        try:
            mic = AudioUtilities.GetMicrophone()
            if not mic:
                return
            interface = mic.Activate(IAudioEndpointVolume._iid_, CLSCTX_ALL, None)
            self._input_volume = cast(interface, POINTER(IAudioEndpointVolume))
        except Exception:
            pass

    def get_sessions(self):
        sessions = []
        seen = set()
        try:
            for s in AudioUtilities.GetAllSessions():
                if s.Process is None:
                    continue
                try:
                    name = s.Process.name()
                    lower = name.lower()
                    if lower in seen or lower in self.BLOCKED_APPS:
                        continue
                    vol = s._ctl.QueryInterface(ISimpleAudioVolume)
                    sessions.append(AudioSession(
                        process_id=s.Process.pid, process_name=name,
                        display_name=self._display_name(name),
                        volume=vol.GetMasterVolume(), is_muted=vol.GetMute()
                    ))
                    seen.add(lower)
                except Exception:
                    continue
        except Exception:
            pass
        return sessions

    def _display_name(self, name):
        lower = name.lower()
        return self.DISPLAY_NAMES.get(lower, name.replace('.exe', '').capitalize())

    def set_session_volume(self, process_name, volume):
        try:
            comtypes.CoInitialize()
        except:
            pass
        volume = max(0.0, min(1.0, volume))
        try:
            target = process_name.lower()
            for s in AudioUtilities.GetAllSessions():
                try:
                    if s.Process and s.Process.name().lower() == target:
                        s._ctl.QueryInterface(ISimpleAudioVolume).SetMasterVolume(volume, None)
                        return True
                except Exception:
                    continue
        except Exception:
            pass
        return False

    def get_master_volume(self):
        if self._master_volume:
            try:
                if hasattr(self._master_volume, 'level'):
                    return self._master_volume.level
                return self._master_volume.GetMasterVolumeLevelScalar()
            except Exception:
                pass
        return 0.0

    def set_master_volume(self, volume):
        volume = max(0.0, min(1.0, volume))
        if self._master_volume:
            try:
                if hasattr(self._master_volume, 'level'):
                    self._master_volume.level = volume
                    return True
                self._master_volume.SetMasterVolumeLevelScalar(volume, None)
                return True
            except Exception:
                pass
        return False

    def get_input_volume(self):
        ctrl = self._input_volume
        if ctrl:
            try:
                return ctrl.GetMasterVolumeLevelScalar()
            except Exception:
                pass
        return 0.0

    def set_input_volume(self, volume):
        volume = max(0.0, min(1.0, volume))
        ctrl = self._input_volume
        if ctrl:
            try:
                ctrl.SetMasterVolumeLevelScalar(volume, None)
                return True
            except Exception:
                pass
        return False

    def register_session_callback(self, callback):
        self._callbacks.append(callback)

    def start_monitoring(self, interval=1.0):
        if self._monitor_thread and self._monitor_thread.is_alive():
            return
        self._running = True
        self._monitor_thread = threading.Thread(target=self._monitor, args=(interval,), daemon=True)
        self._monitor_thread.start()

    def stop_monitoring(self):
        self._running = False
        if self._monitor_thread:
            self._monitor_thread.join(timeout=2.0)
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

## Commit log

2026-01-24 First Revision
    [Custom-Mixer-ESP32.kicad_pcb, Custom-Mixer-ESP32.kicad_sch]
2026-01-25 Add Gerber and drill files for Custom-Mixer-ESP32 PCB
    Initial commit of all generated Gerber, drill, and job files for the Custom-Mixer-ESP32 PCB design. These files are required for PCB fabrication and assembly.
    [Custom-Mixer-ESP32-B_Cu.gbr, Custom-Mixer-ESP32-B_Mask.gbr, Custom-Mixer-ESP32-B_Paste.gbr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]
2026-01-25 Initialize README with project details and BOM
    Added project description, bill of materials, and hardware details.
2026-01-25 Update README with schematic and PCB images
    Added schematic and PCB images to the README.
2026-01-25 Add assembly PDF and board2pdf config for ESP32 PCB
    Added Custom-Mixer-ESP32__Assembly.pdf and board2pdf.config.ini for generating assembly documentation. Updated the PCB file to change drill shape output settings. Assembly PDF is also included in the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
    [Custom-Mixer-ESP32.kicad_pcb]
2026-01-25 Add BOM and project CSV files, update .gitignore
    Added BOM.csv and Custom-Mixer-ESP32.csv to track bill of materials and project components. Updated .gitignore to allow CSV and XML files to be committed, enabling version control of exported BOMs.
    [BOM.csv]
2026-01-25 Revise README for Custom Mixer ESP32 project
    Updated project name and clarified functionality. Added links for components and reorganized sections for better clarity.
2026-01-25 Redo File directory and 2nd revision of PCB and schematic
    [2717.step, Complete Model.step, Container.step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]
2026-01-25 Add Adafruit CircuitPython libraries to firmware
    Added a large set of Adafruit CircuitPython .mpy and __init__.py libraries to the Firmware/lib directory. This update integrates support for a wide range of sensors, displays, communication modules, 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
2026-01-25 Update BOM: adjust quantities and add multiplexer
    Reduced ceramic capacitor quantity from 15 to 10, removed resistor line, added TCA9548A I2C multiplexer, and updated total cost in the BOM.csv file.
    [BOM.csv]
2026-01-25 Remove unused wires from schematic
    Deleted several unused wire
    [Custom-Mixer-ESP32.kicad_sch]
2026-01-27 Update README with new images and BOM entry
    Added additional images for PCB and CAD sections, and included a new component in the BOM.
2026-01-29 Cad Revision
    [Case.step, Complete Model.step, Container.step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]
2026-01-29 Connect potentiometer pads to +3V3 and clean up nets
    Updated RV2, RV3, and RV4 potentiometer pad 3 connections from unconnected nets to +3V3. Cleaned up and renumbered net assignments throughout the schematic, removed unused/unconnected net definitions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
    [Custom-Mixer-ESP32.kicad_pcb]
2026-01-29 Add +3V3 power symbols and update PCB routing
    Added multiple +3V3 power symbols to the schematic for improved clarity and power distribution. Updated PCB routing for nets 1 and 7, including new segments, vias, and changes to net connections for 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
    [Custom-Mixer-ESP32.kicad_pcb, Custom-Mixer-ESP32.kicad_sch]
2026-02-02 Add MCP23017 PCB project & update KiCad libs
    Add Adafruit MCP23017 GPIO Expander KiCad project (board, schematic, MCP23017 symbol/footprint, README, license, assets and pretty library parts). Add OLED 128x64 symbol/module files. Modify Custom-M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
    [Adafruit MCP23017 GPIO Expander.brd, Adafruit MCP23017 GPIO Expander.sch, Custom-Mixer-ESP32.kicad_pcb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]
2026-02-06 Rewire and create custom footprint
    [Custom-Mixer-ESP32.kicad_pcb, Custom-Mixer-ESP32.kicad_sch]
2026-02-13 Complete Wire Revamp
    [Custom-Mixer-ESP32.kicad_pcb, Custom-Mixer-ESP32.kicad_sch]
2026-02-13 PCB rework completed
    [2.4_TFT_Display.step, 2717.step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]
2026-02-14 Revise README for Custom Mixer ESP32 to v2.0
    Updated project details to reflect new features and components in version 2.0, including additional switches and improved functionality.
2026-02-14 PCB Completion and GerberFiles Created
    [Case.step, Complete Model.step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]
2026-02-15 Update BOM: parts, quantities, prices, and total
    Adjust BOM entries and pricing: lower ceramic capacitor unit price; replace ESP32-DEVKITC with ESP32-S3-WROOM-1; add resistor packs, premium and standard knobs, MCP23017 I2C expander, a 2.2" TFT screen and used Cherry MX switches; remove 0.91" OLED and TCA9548A multiplexer. Update PCB manufacturing line (new item and qty), add 3D printing and shipping estimates, and recalculate total (was £58.37, now £82.74).
    [BOM.csv]
2026-03-21 Restructure and add firmware
    [Custom-Mixer-ESP32.csv, Custom-Mixer-ESP32.step]
2026-03-21 Update BOM and some parts of readme
    [BOM.csv]

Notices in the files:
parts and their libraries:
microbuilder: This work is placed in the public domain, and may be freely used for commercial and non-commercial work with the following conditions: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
